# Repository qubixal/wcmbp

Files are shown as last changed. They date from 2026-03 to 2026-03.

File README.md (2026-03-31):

# Water Cooled MacBookPro (WCMBP)
> _this is part of a submission to Blueprint Hack Club._

**Hello!** I'm aiming to DIY the First True* Liquid Cooled Macbook utilising a sub-2.5mm Liquid Cooling Block, as well as creating the first Active Same-Level Hybrid Air-Liquid Cooling System In Consumer Electronics.
The first part of this readme will be a short introduction before this project is explained in more depth.
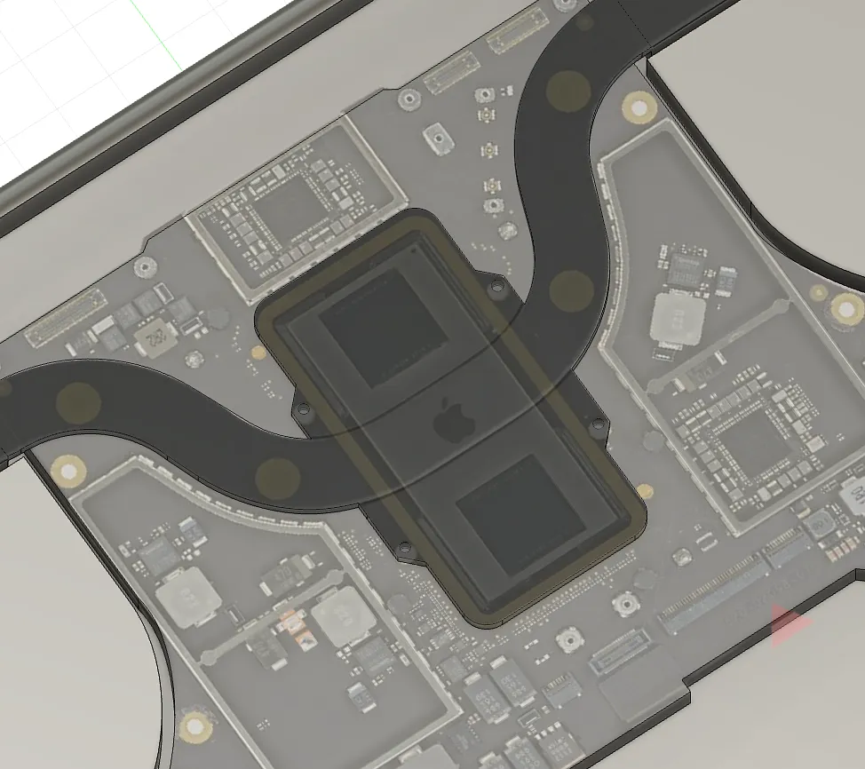
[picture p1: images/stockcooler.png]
Stock Cooler

_render of the stock cooler of the Macbook Pro A2442._

## Function / Use
Similar to a traditional Desktop PC AIO, it features a pump, two fans (one blower one exhaust) and a modified refrigerator heatsink for a small size. 
<br>To use this project, simply plug in the quick disconnect tubing and plug the usbc line into a Macbook that has been prefitted with the heatsink and watch temps drop. 

## Why did I start this project?
I've always wanted to start making something but never found the determination to. 
My first attempt happened last year with me challenging myself to build the smallest drone i could, though those plans were cut short by my lack of experience and shipping problems (negotiating 4 months for the pcb) that destroyed my motivation. 
I wanted to push for a pioneer and revolutionary idea that improves technology, and had an idea at the end of last year to create the world's first true liquid cooled Macbook. 

I hope to make a high quality video out of this project too!
<br> **Thank you for reviewing this project.**

note: this repository is placed under CC BY-NC-ND.

## Hardware (Cooler)
The concept is simple, just pull water over the processor ...
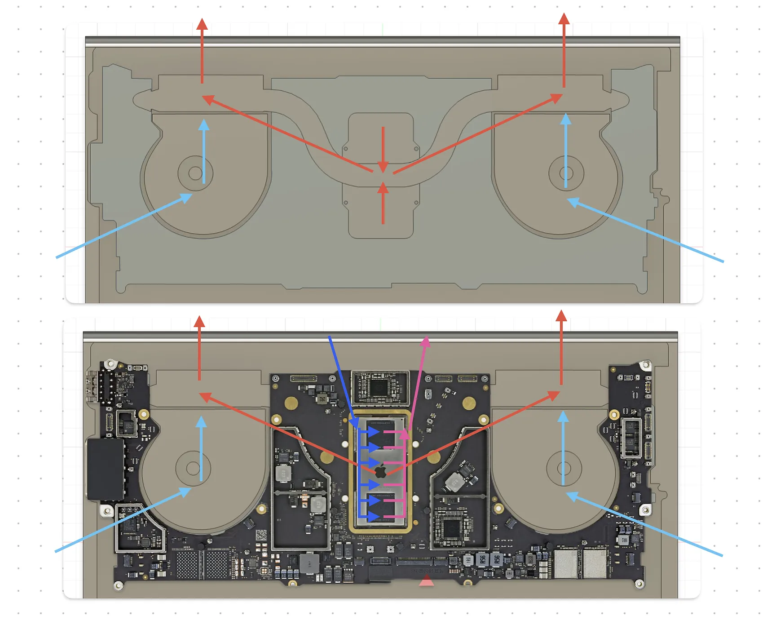
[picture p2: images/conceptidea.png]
Concept Sketch

The first design used parallel channels running from a supply manifold to a drain manifold, shortening single channels to reduce pressure drop.
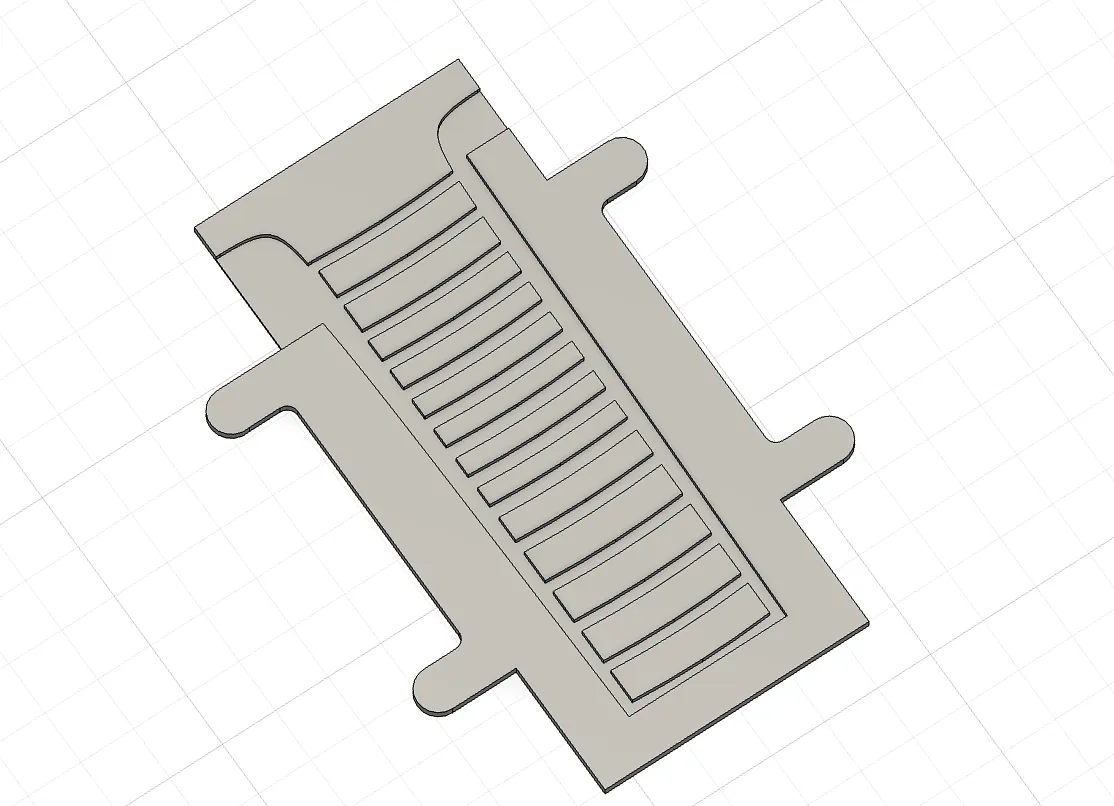
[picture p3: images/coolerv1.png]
First Block Design

To assist with water flow better, the second design smoothed out corners of the first.
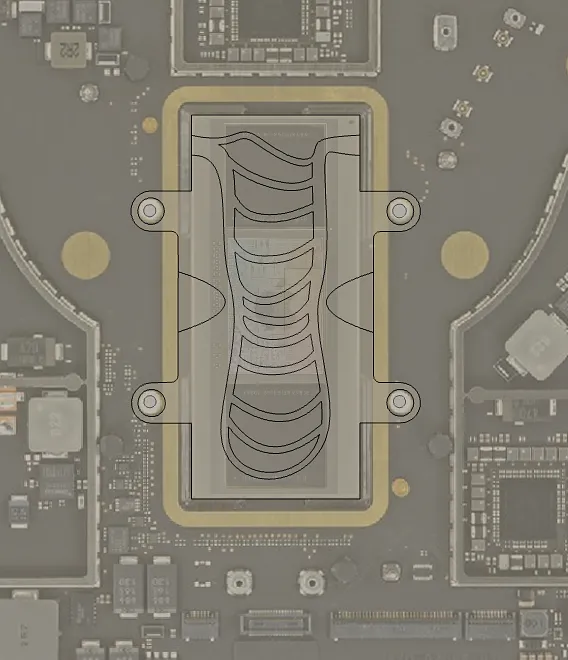
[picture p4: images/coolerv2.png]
Second Block Design


## PCB
This project is powered using the STM32G431CBT6, as my friend also happen to be building a project of his using this chip.
The schematics are as follows.
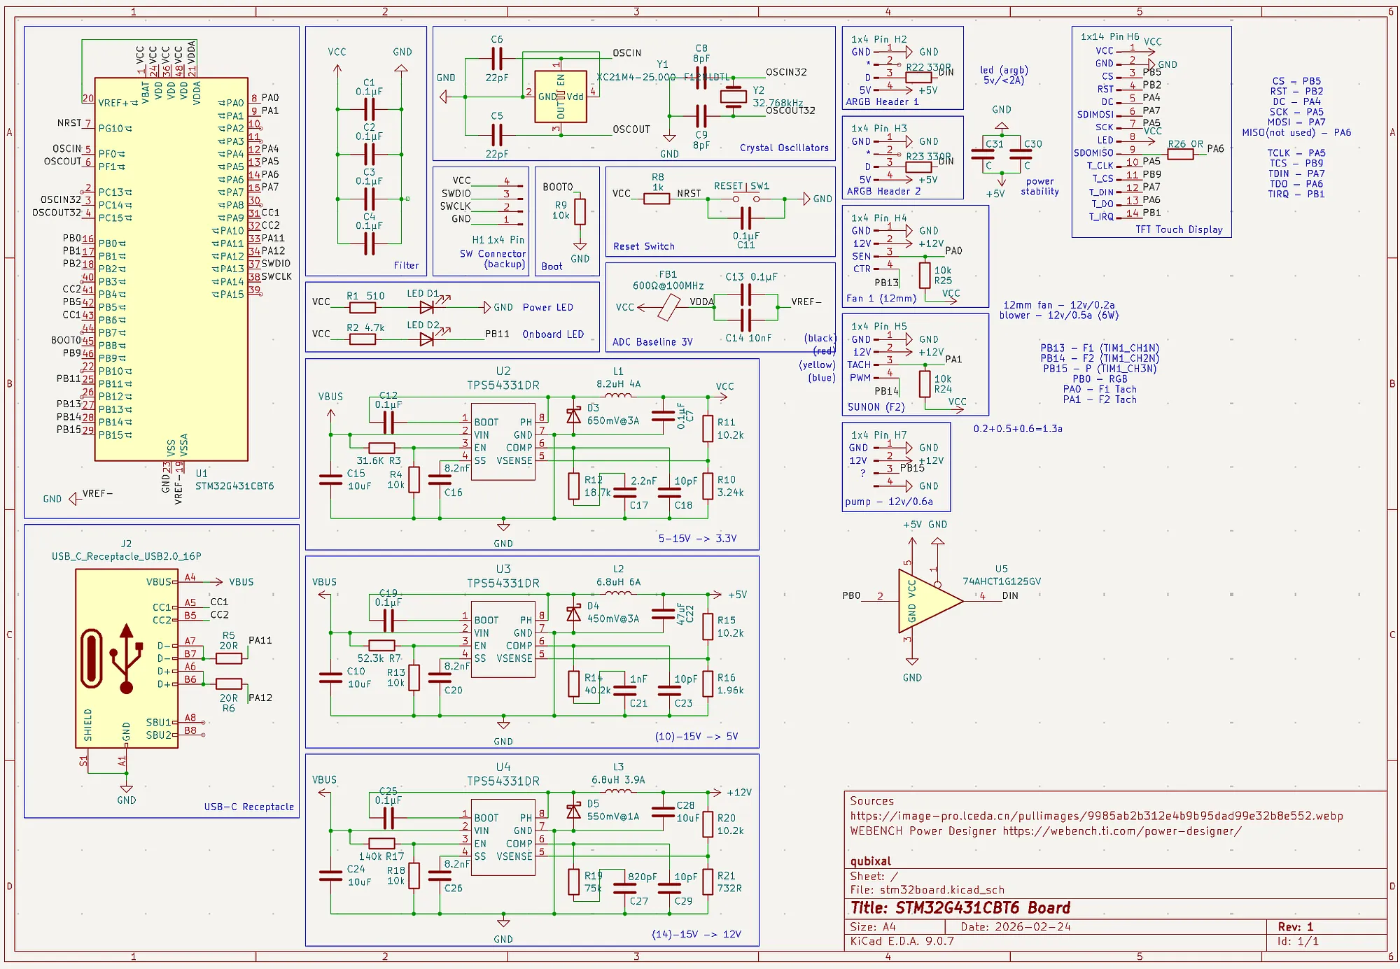
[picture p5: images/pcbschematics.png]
Alt text description

There are a few errors in the schematic design, such as flashing components being forgotten T_T but I'm trying to find a workaround without buying another board.
The wiring is relatively straightforward, all the power supply is at the bottom and the main chip components to the centre, while peripherals are connected to the left.
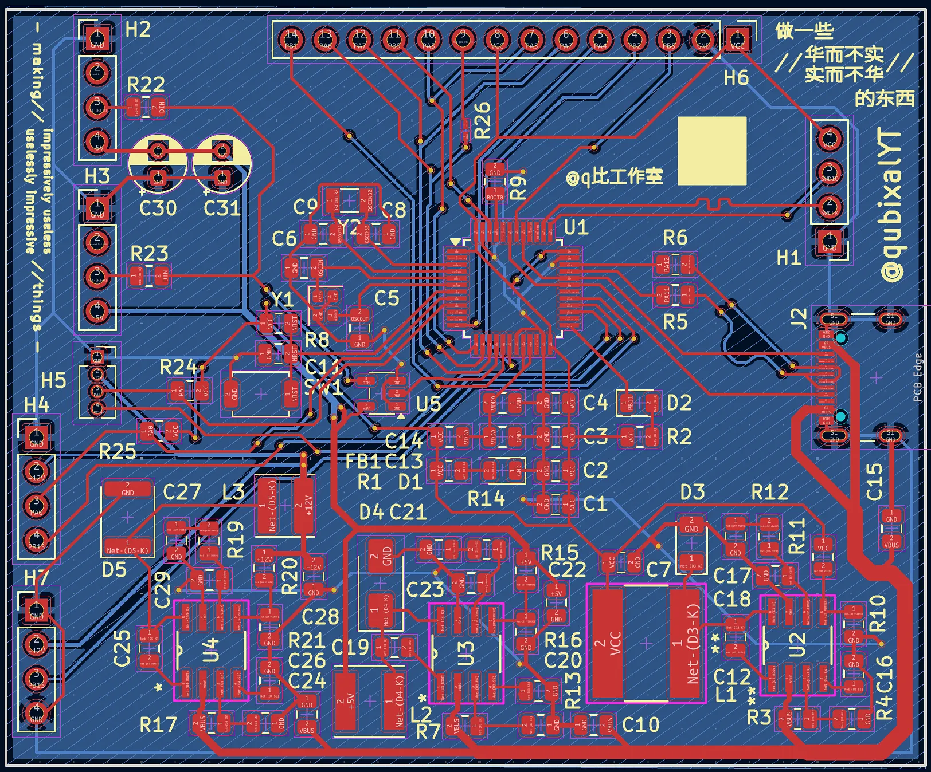
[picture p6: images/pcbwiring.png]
Current wiring

I have finished soldering the board (only rich people can afford stencil T-T) and debugging USB data issues.
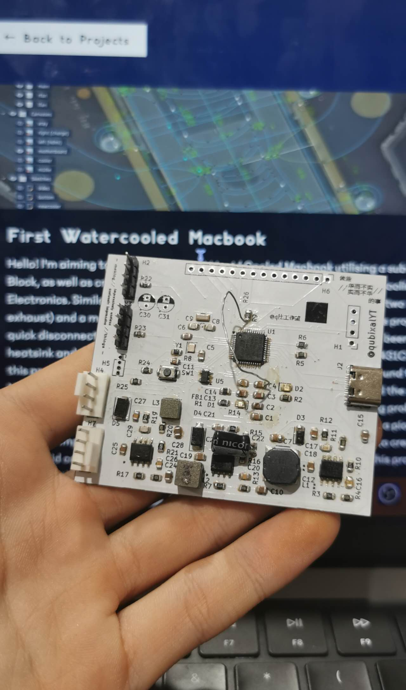
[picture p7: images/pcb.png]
PCB Board


## Case
Original case
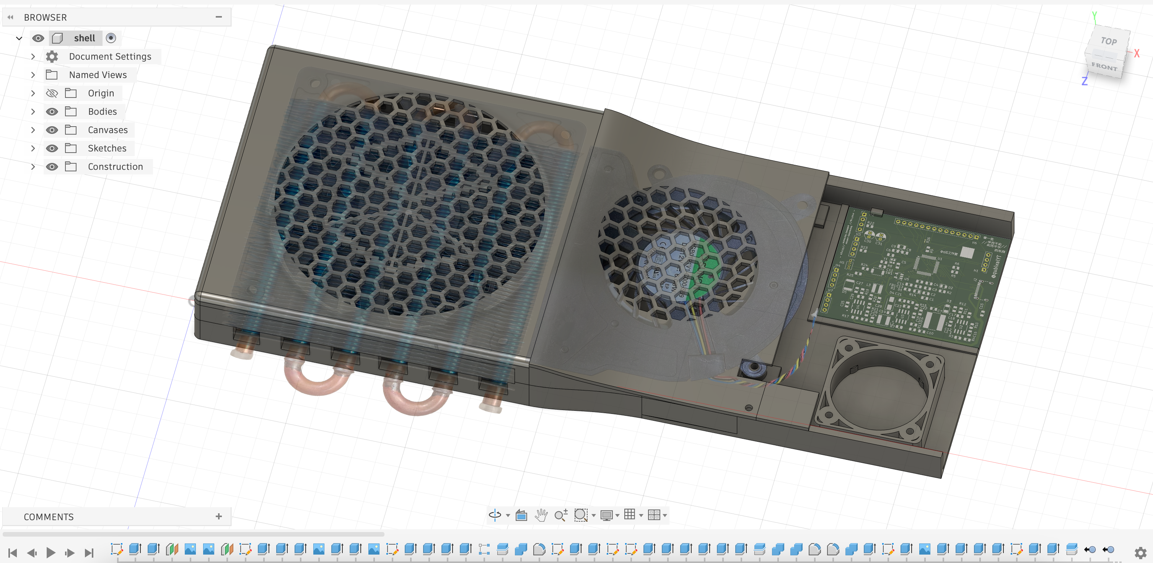
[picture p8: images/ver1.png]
Original casing

Somehow, not a **single** dimension fit. A round of revision and rebuilding the entire project again, ver2 is born.
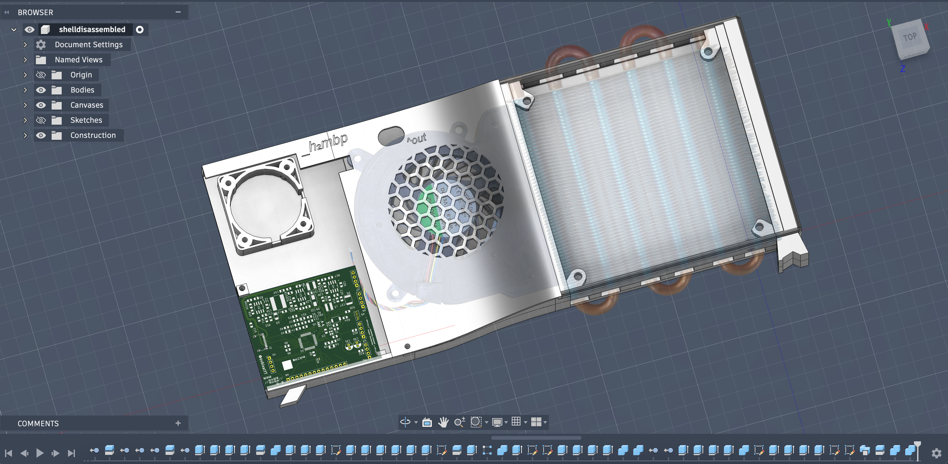
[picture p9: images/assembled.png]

The whole thing can be 3D printed in a few pieces.
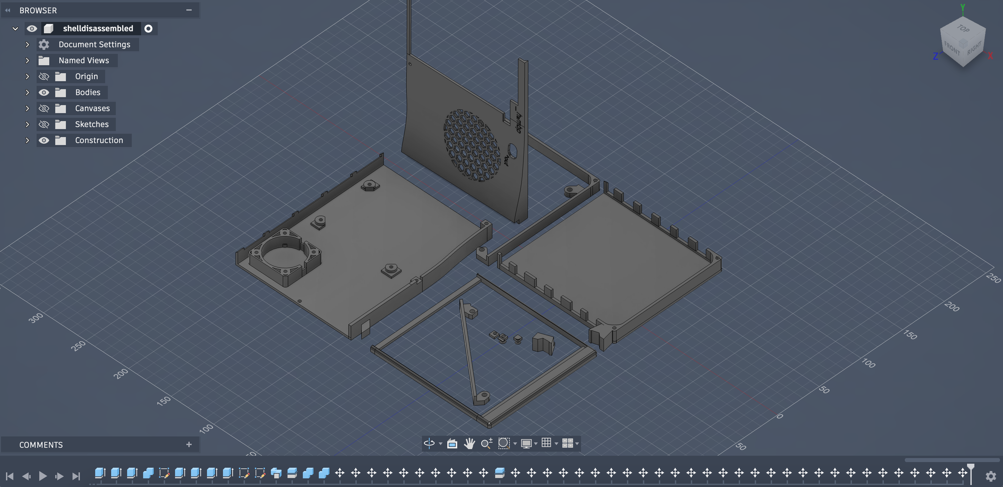
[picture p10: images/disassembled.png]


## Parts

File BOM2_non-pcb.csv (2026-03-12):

Title |  | Multiple | ¥ (CNY) | Link
Barrow 多色PC电脑水冷专用浓缩型冷液 可勾兑1000ML去离子导热液 [交易快照] | Cooling Liquid | 1 | 47.04 | https://item.taobao.com/item.htm?id=655366533729
ARGB机箱装饰5v三针灯条 LED幻彩变色AURA主板神光同步氛围灯带 [交易快照] | ARGB Light | 2 | 33.9 | https://item.taobao.com/item.htm?id=891034010727
亚克力薄片双面加硬亚克力板定制加工diy手工材料裁剪打孔塑料板 [交易快照] | Acrylic Sheet | 1 | 20 | https://item.taobao.com/item.htm?id=1004927544275
笔记本散热铜管超薄导热管平板电脑散热管手机散热冷却管厚:1.0mm [交易快照] | Copper Heatpipe | 4 | 46.4 | https://item.taobao.com/item.htm?id=595853542727
导热胶粘性 导热胶固化粘接导热管铜管 强粘性硅胶ST-988*5克 [交易快照] | Thermal Plaster | 3 | 16.7 | https://item.taobao.com/item.htm?id=19004921338
笔记本电脑散热片纯紫铜散热鳍片翅片热管散热片长度可以DIY改造 [交易快照] | Copper Heatsink | 2 | 44.6 | https://item.taobao.com/item.htm?id=556392308394
彩色液晶屏模块1.8/2.0/2.4/2.8/3.2/3.5寸TFT触摸显示屏SPI彩屏 [交易快照] | TFT Screen | 1 | 36.51 | https://item.taobao.com/item.htm?id=559064754163
704/705/706RTV硅橡胶耐高低温单组份室温固化硅胶驱动电子电器胶 [交易快照] | RTV Silicone | 1 | 11 | https://item.taobao.com/item.htm?id=850193498133
建准原装SUNON MGB0121V1-C000-S99 12V 6.08W一体机散热风扇 [交易快照] | SUNON Fan | 1 | 30 | https://item.taobao.com/item.htm?id=886873268094
笔记本水冷双向止水阀双自锁快速接头模型液压油管接头M5M3螺纹铜 [交易快照] | Fitting 1 | 2 | 89 | https://item.taobao.com/item.htm?id=728084749755
笔记本水冷双向止水阀双自锁快速接头模型液压油管接头M5M3螺纹铜 [交易快照] | Fitting 2 | 2 |  | https://item.taobao.com/item.htm?id=728084749755
不锈钢注塑螺母 M3M4M5M6通孔预埋滚花圆镶嵌国标 直纹 [交易快照] | Fitting 3 | 1 | 7.9 | https://item.taobao.com/item.htm?id=833692892860
不锈钢注塑螺母 M3M4M5M6通孔预埋滚花圆镶嵌国标 直纹 [交易快照] | Fitting 4 | 1 |  | https://item.taobao.com/item.htm?id=833692892860
透明硅胶管 内径8mm 外径9/10/11/12/13/14/16mm食品医用 冷水管 [交易快照] | Tubing (8x10) | 1 | 4.8 | https://item.taobao.com/item.htm?id=38955505261
透明硅胶管软管食品级0.5/1/1.2/1.3/1.6/1.8/2mm毛细管耐高温 [交易快照] | Tubing (1x1.6) | 1 |  | https://item.taobao.com/item.htm?id=40127147980
万向直角宝塔弯头4-M6X1公制螺纹8-M8X1硅胶管管12-M14X1.5冷水管 [交易快照] | Fitting 5 | 2 | 13.57 | https://item.taobao.com/item.htm?id=889054938293
黄铜卡套转快拧直通铜管转气管金属管转软管PU管尼龙管等变径直接 [交易快照] | Fitting 6 | 2 | 16.6 | https://item.taobao.com/item.htm?id=669600619157
小型宝塔1mm插管2mm宝塔1.5 2.5 3 4 1/16管1/8mm 毛细管宝塔接头 [交易快照] | Fitting 7 | 2 | 9.78 | https://item.taobao.com/item.htm?id=803566514786
铜管铝翅片式微型迷你冷凝器小型制冷蒸发器风冷冰箱散热器带风扇 [交易快照] | Radiator | 1 | 37 | https://item.taobao.com/item.htm?id=779852682900
YBO盈博12cm超薄风扇智能调速散热器实力工厂质保一年 [交易快照] | ococoo fan | 1 | 129 | https://item.taobao.com/item.htm?id=1000588580689
YBO盈博水泵工业水冷OC-P67F P67E P27水冷水箱散热医疗美容激光 [交易快照] | Pump | 1 |  | https://item.taobao.com/item.htm?id=827068254010
T2紫铜板加工CNC加工数控车床激光切割线割折弯焊接电镀非标定制 [交易快照] | Custom Copper Block | 1 | 130 | https://item.taobao.com/item.htm?id=994865476571

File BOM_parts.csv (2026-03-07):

Index | LCSC# | MPN | Manufacturer | Package | Customer # | Description | RoHS | Quantity | MOQ | Multiple | Unit Price($) | Extended Price($) | Product Link
1 | C21519 | MPZ2012S601AT000 | TDK | 0805 |  | 600Ω@100MHz 1 Line Ferrite Bead 0805 2A 100mΩ | yes | 10 | 10 | 10 | 0.0245 | 0.25 | https://www.lcsc.com/product-detail/C21519.html
2 | C1710 | CL21B103KBANNNC | Samsung Electro-Mechanics | 0805 |  | 10nF ±10% 50V Ceramic Capacitor X7R 0805 | yes | 50 | 50 | 50 | 0.0065 | 0.33 | https://www.lcsc.com/product-detail/C1710.html
3 | C17402 | 0805W8F1022T5E | UNI-ROYAL | 0805 |  | 10.2kΩ ±1% 125mW 0805 Thick Film Resistor | yes | 100 | 100 | 100 | 0.0024 | 0.24 | https://www.lcsc.com/product-detail/C17402.html
4 | C2933414 | FRC0805F3241TS | FOJAN | 0805 |  | 3.24kΩ ±1% 125mW 0805 Thick Film Resistor | yes | 100 | 100 | 100 | 0.0019 | 0.19 | https://www.lcsc.com/product-detail/C2933414.html
5 | C576982 | CC0805JRNPOCBN100 | YAGEO | 0805 |  | 10pF ±5% 1kV Ceramic Capacitor 0805 | yes | 20 | 20 | 20 | 0.0254 | 0.51 | https://www.lcsc.com/product-detail/C576982.html
6 | C36576 | 0805B222K500NT | FH | 0805 |  | 2.2nF ±10% 50V Ceramic Capacitor X7R 0805 | yes | 20 | 20 | 20 | 0.0051 | 0.10 | https://www.lcsc.com/product-detail/C36576.html
7 | C49655954 | GR0805F18K7T5G00 | GiantOhm | 0805 |  | 125mW 18.7kΩ 150V Thick Film Resistor ±100ppm/℃ ±1% 0805 Chip Resistor - Surface Mount RoHS | yes | 100 | 100 | 100 | 0.0016 | 0.16 | https://www.lcsc.com/product-detail/C49655954.html
8 | C154751 | SBR3U60P1-7 | DIODES | PowerDI-123 |  | 80A 60V 1 Independent 650mV@3A 3A PowerDI-123 Single Diodes RoHS | yes | 5 | 5 | 5 | 0.1357 | 0.68 | https://www.lcsc.com/product-detail/C154751.html
9 | C2041695 | SRN8040-8R2Y | BOURNS | SMD,8.2x7.9mm |  | 3.7A 8.2uH 4A 45mΩ ±30% SMD,8.2x7.9mm Fixed Inductors RoHS | yes | 1 | 1 | 1 | 0.5130 | 0.51 | https://www.lcsc.com/product-detail/C2041695.html
10 | C5128355 | 08055C822KAT2A | Kyocera AVX | 0805 |  | 8.2nF X7R ±10% 50V 0805 Ceramic Capacitors RoHS | yes | 10 | 10 | 10 | 0.0326 | 0.33 | https://www.lcsc.com/product-detail/C5128355.html
11 | C2930231 | FRC0805J103TS | FOJAN | 0805 |  | 10kΩ ±5% 125mW 0805 Thick Film Resistor | yes | 100 | 100 | 100 | 0.0018 | 0.18 | https://www.lcsc.com/product-detail/C2930231.html
12 | C2930156 | FRC0805F3162TS | FOJAN | 0805 |  | 31.6kΩ ±1% 125mW 0805 Thick Film Resistor | yes | 100 | 100 | 100 | 0.0020 | 0.20 | https://www.lcsc.com/product-detail/C2930156.html
13 | C48579607 | 0805X7R106K250NT | AIDE CAPACITOR | 0805 |  | 10uF ±10% 25V Ceramic Capacitor X7R 0805 | yes | 10 | 10 | 10 | 0.0298 | 0.30 | https://www.lcsc.com/product-detail/C48579607.html
14 | C2933465 | FRC0805F5232TS | FOJAN | 0805 |  | 52.3kΩ ±1% 125mW 0805 Thick Film Resistor | yes | 100 | 100 | 100 | 0.0021 | 0.21 | https://www.lcsc.com/product-detail/C2933465.html
15 | C5563736 | MBRA340T3G-FS | FUXINSEMI | SMA(DO-214AC) |  | Diode Independent 40V 3A Surface Mount SMA(DO-214AC) | yes | 5 | 5 | 5 | 0.0733 | 0.37 | https://www.lcsc.com/product-detail/C5563736.html
16 | C49261459 | AAPS0550M6R8F | Coilank | SMD,5.5x5.3mm |  | 6.4A 6.8uH 28.6mΩ 6.6A ±20% SMD,5.5x5.3mm Fixed Inductors RoHS | yes | 1 | 1 | 1 | 0.8602 | 0.86 | https://www.lcsc.com/product-detail/C49261459.html
17 | C2933438 | FRC0805F4022TS | FOJAN | 0805 |  | 40.2kΩ ±1% 125mW 0805 Thick Film Resistor | yes | 100 | 100 | 100 | 0.0020 | 0.20 | https://www.lcsc.com/product-detail/C2933438.html
18 | C1791 | CL21C102JBCNNNC | Samsung Electro-Mechanics | 0805 |  | 1nF ±5% 50V Ceramic Capacitor C0G 0805 | yes | 10 | 10 | 10 | 0.0088 | 0.09 | https://www.lcsc.com/product-detail/C1791.html
19 | C2930163 | FRC0805F1961TS | FOJAN | 0805 |  | 1.96kΩ ±1% 125mW 0805 Thick Film Resistor | yes | 100 | 100 | 100 | 0.0019 | 0.19 | https://www.lcsc.com/product-detail/C2930163.html
20 | C5378487 | FEXL0430A-6R8M | cjiang | SMD,4.1x4.1mm |  | 3.9A 6.8uH 3.6A 74.1mΩ ±20% SMD,4.1x4.1mm Fixed Inductors RoHS | yes | 1 | 1 | 1 | 1.1966 | 1.20 | https://www.lcsc.com/product-detail/C5378487.html
21 | C2837270 | SS14 | JSMSEMI | SMA(DO-214AC) |  | Diode 40V 1A Surface Mount SMA(DO-214AC) | yes | 50 | 50 | 50 | 0.0108 | 0.54 | https://www.lcsc.com/product-detail/C2837270.html
22 | C2933315 | FRC0805F1403TS | FOJAN | 0805 |  | 140kΩ ±1% 125mW 0805 Thick Film Resistor | yes | 100 | 100 | 100 | 0.0019 | 0.19 | https://www.lcsc.com/product-detail/C2933315.html
23 | C17819 | 0805W8F7502T5E | UNI-ROYAL | 0805 |  | 75kΩ ±1% 125mW 0805 Thick Film Resistor | yes | 100 | 100 | 100 | 0.0020 | 0.20 | https://www.lcsc.com/product-detail/C17819.html
24 | C458928 | 0805B821K101CT | Walsin | 0805 |  | 820pF ±10% 100V Ceramic Capacitor X7R 0805 | yes | 50 | 50 | 50 | 0.0016 | 0.08 | https://www.lcsc.com/product-detail/C458928.html
25 | C327296 | RC0805FR-07732RL-S | YAGEO | 0805 |  | 125mW 732Ω 150V Thick Film Resistor ±100ppm/℃ ±1% 0805 Chip Resistor - Surface Mount RoHS | yes | 100 | 100 | 100 | 0.0024 | 0.24 | https://www.lcsc.com/product-detail/C327296.html
26 | C52140417 | 74AHCT1G125GV | MDD(Microdiode Semiconductor) | SOT-23-5L |  | 4.5V~5.5V 1 1 1ns@4.5V 40uA SOT-23-5L Buffers, Drivers, Receivers, Transceivers RoHS | yes | 1 | 1 | 1 | 0.0741 | 0.07 | https://www.lcsc.com/product-detail/C52140417.html
27 | C19795120 | 470533000 | MOLEX | P=2.54mm |  | 1 4P 4 2.54mm 4A 500V 1x4P P=2.54mm Headers, Male Pins RoHS | yes | 5 | 5 | 5 | 0.3702 | 1.85 | https://www.lcsc.com/product-detail/C19795120.html
28 | C529355 | STM32G431CBT6 | ST | LQFP-48(7x7) |  | ARM Cortex-M4F 32 Bit 170MHz 38 LQFP-48(7x7) Microcontrollers RoHS | yes | 5 | 1 | 1 | 3.0856 | 15.43 | https://www.lcsc.com/product-detail/C529355.html
29 | C9865 | TPS54331DR | TI | SOIC-8 |  | 570kHz Buck Adjustable 800mV~25V 3A 3.5V~28V SOIC-8 Voltage Regulators - DC DC Switching Regulators RoHS | yes | 5 | 5 | 5 | 0.2767 | 1.38 | https://www.lcsc.com/product-detail/C9865.html
30 | C5368707 | 1.25mm-4P ZZ-MS | SHOU HAN | Through Hole,P=1.25mm |  | Connector Header 4 position 1.25mm Pitch 1A Through Hole -25℃~+85℃ | yes | 20 | 20 | 20 | 0.0230 | 0.46 | https://www.lcsc.com/product-detail/C5368707.html
31 | C97606 | SC-32S32.768kHz20PPM12.5pF | Seiko | SMD3215-2P |  | Crystal 32.768kHz ±20ppm 12.5pF SMD3215-2P | yes | 5 | 5 | 5 | 0.1828 | 0.91 | https://www.lcsc.com/product-detail/C97606.html
32 | C49234124 | HX 3x4x2-2P-1.6N TACTILE SWITCH | hanxia | SMD,4x3mm |  | Tactile Switch SPST 160gf 2mm SMD (SMT) Tab 4mm x 3mm Surface Mount | yes | 20 | 20 | 20 | 0.0192 | 0.38 | https://www.lcsc.com/product-detail/C49234124.html
33 | C17673 | 0805W8F4701T5E | UNI-ROYAL | 0805 |  | 4.7kΩ ±1% 125mW 0805 Thick Film Resistor | yes | 100 | 100 | 100 | 0.0019 | 0.19 | https://www.lcsc.com/product-detail/C17673.html
34 | C25293 | 0805W8J0200T5E | UNI-ROYAL | 0805 |  | 20Ω ±5% 125mW 0805 Thick Film Resistor | yes | 100 | 100 | 100 | 0.0019 | 0.19 | https://www.lcsc.com/product-detail/C25293.html
35 | C25170728 | YLED0805G | YONGYUTAI | 0805 |  | Emerald Green 525nm LED Indication - Discrete 2.4V~3.1V 0805 | yes | 50 | 50 | 50 | 0.0084 | 0.42 | https://www.lcsc.com/product-detail/C25170728.html
36 | C476766 | C0805B104K500NT | TORCH | 0805 |  | 100nF ±10% 50V Ceramic Capacitor X7R 0805 | yes | 25 | 25 | 25 | 0.0034 | 0.09 | https://www.lcsc.com/product-detail/C476766.html
37 | C28323 | CL21B105KBFNNNE | Samsung Electro-Mechanics | 0805 |  | 1uF ±10% 50V Ceramic Capacitor X7R 0805 | yes | 20 | 20 | 20 | 0.0100 | 0.20 | https://www.lcsc.com/product-detail/C28323.html
38 | C519944 | CC0805CRNPO9BN8R0 | YAGEO | 0805 |  | 8pF 50V Ceramic Capacitor 0805 | yes | 50 | 50 | 50 | 0.0083 | 0.42 | https://www.lcsc.com/product-detail/C519944.html
39 | C1804 | CL21C220JBANNNC | Samsung Electro-Mechanics | 0805 |  | 22pF ±5% 50V Ceramic Capacitor C0G 0805 | yes | 50 | 50 | 50 | 0.0096 | 0.48 | https://www.lcsc.com/product-detail/C1804.html
40 | C3021118 | TPMIC5365-3.3YC5 | TECH PUBLIC | SOT-353 |  | 3.3V 5.5V Positive Fixed SOT-353 Voltage Regulators - Linear, Low Drop Out (LDO) Regulators RoHS | yes | 10 | 5 | 5 | 0.1359 | 1.36 | https://www.lcsc.com/product-detail/C3021118.html
41 | C3034312 | XC21M4-25.000-F12NLDTL | HCI | SMD2016-4P |  | Crystal 25MHz ±10ppm 12pF 100Ω SMD2016-4P | yes | 10 | 5 | 5 | 0.0898 | 0.90 | https://www.lcsc.com/product-detail/C3034312.html

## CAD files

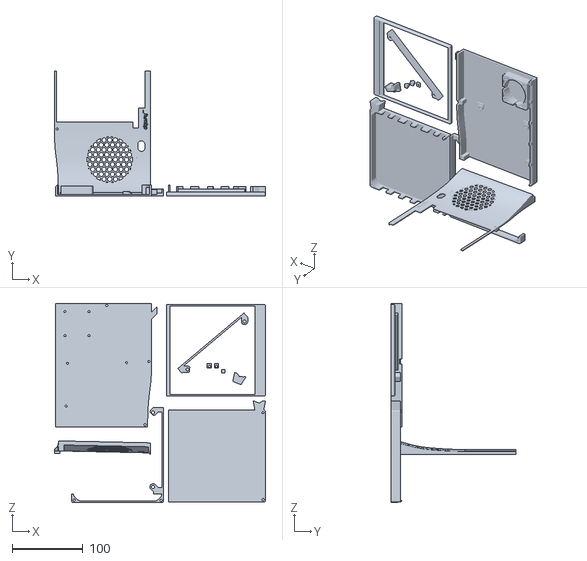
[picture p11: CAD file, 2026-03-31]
shelldisassembled.stl
298.9 x 177.8 x 282.4

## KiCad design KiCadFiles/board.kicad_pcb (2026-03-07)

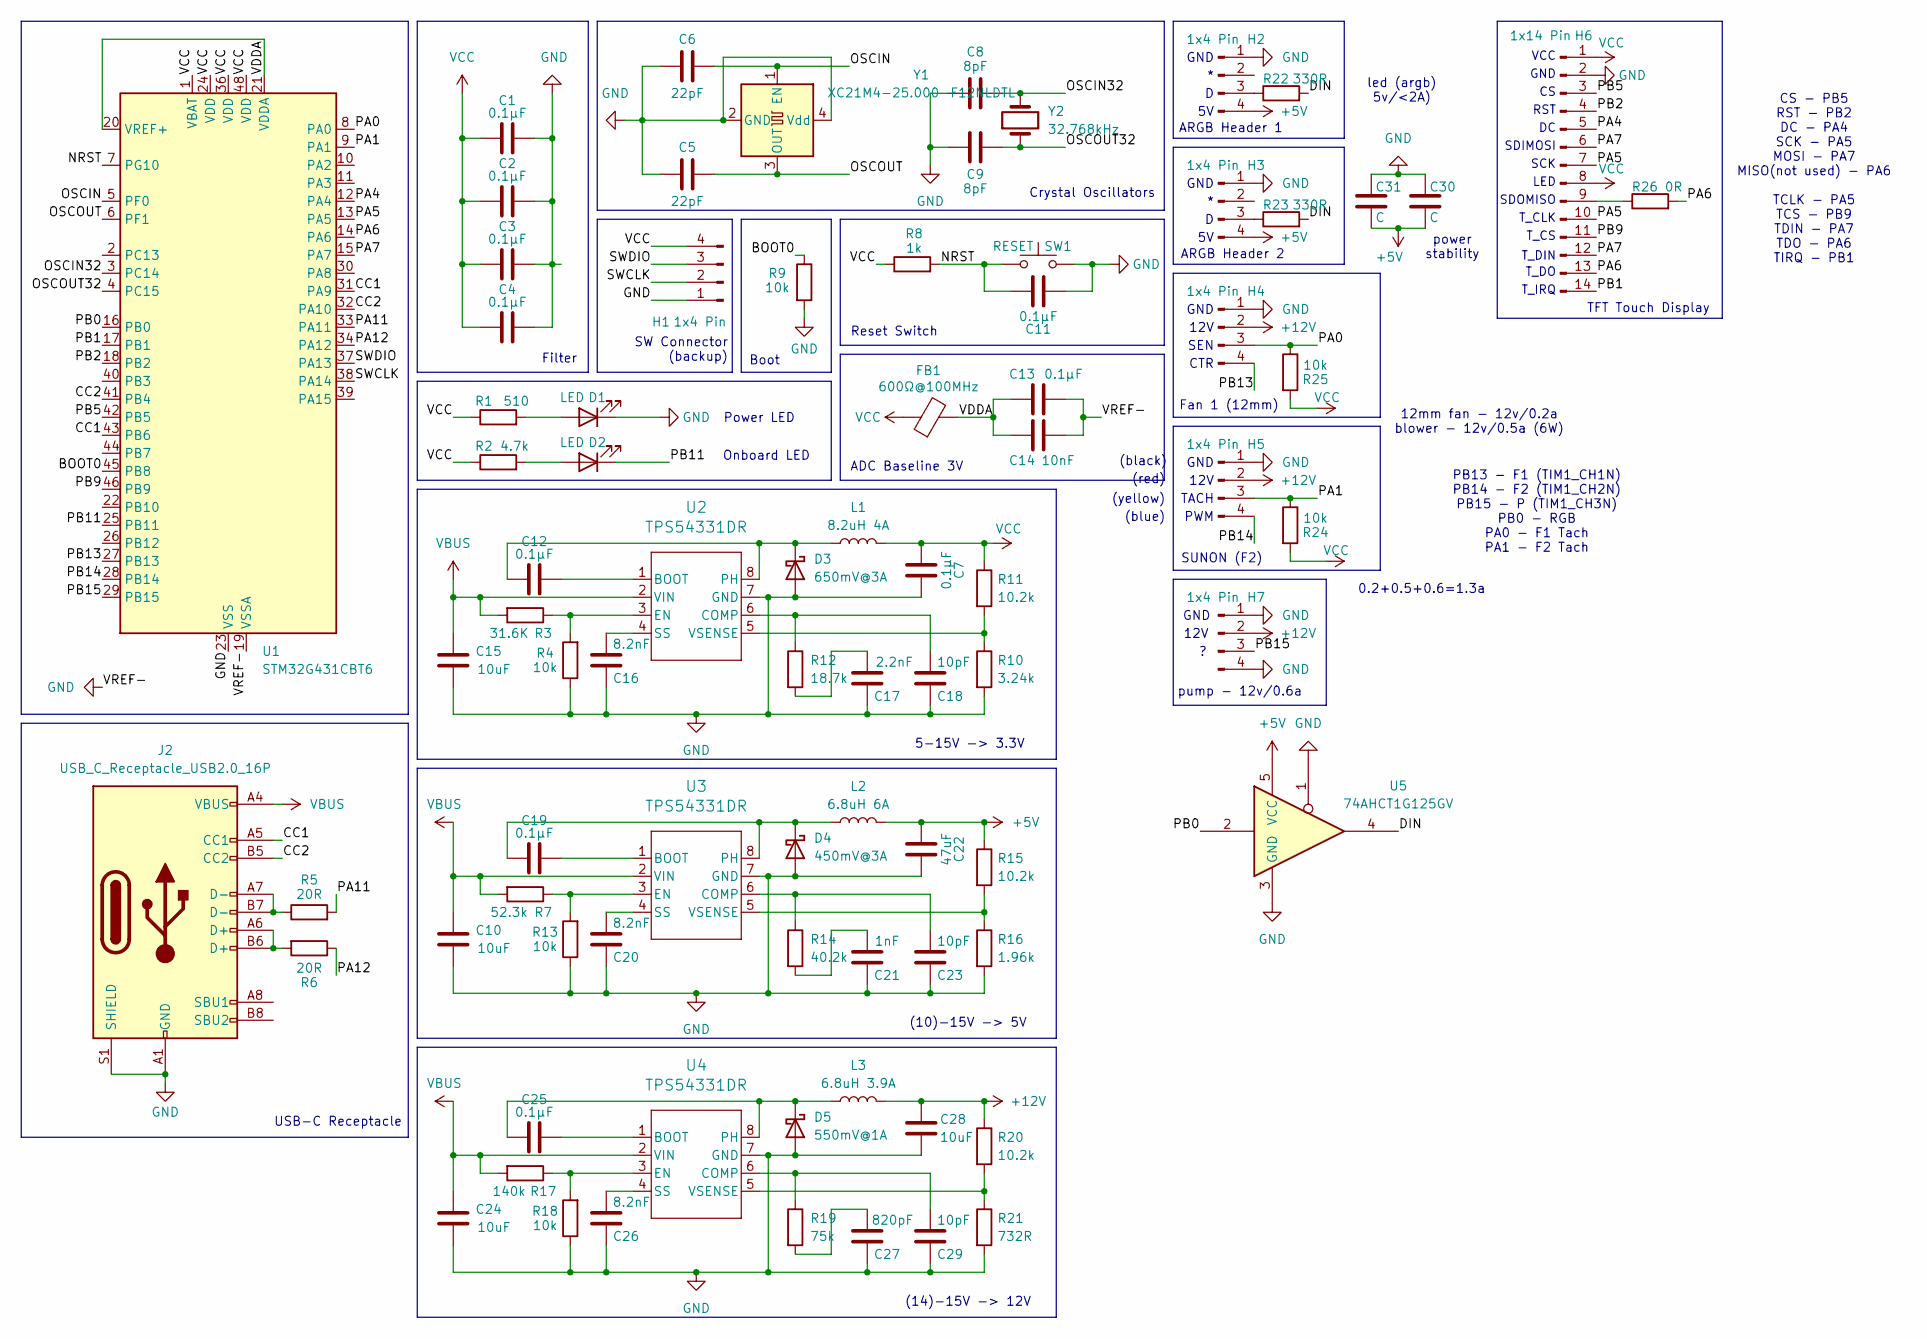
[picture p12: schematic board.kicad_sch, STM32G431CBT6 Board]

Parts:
C1, C2, C3, C4, C7, C11, C12, C13, C19, C25: 0.1μF; C_0805_2012Metric
C5, C6: 22pF; C_0805_2012Metric
C8, C9: 8pF; C_0805_2012Metric
C10, C15, C24, C28: 10uF; C_0805_2012Metric
C14: 10nF; C_0805_2012Metric
C16, C20, C26: 8.2nF; C_0805_2012Metric
C17: 2.2nF; C_0805_2012Metric
C18, C23, C29: 10pF; C_0805_2012Metric
C21: 1nF; C_0805_2012Metric
C22: 47uF; C_0805_2012Metric
C27: 820pF; C_0805_2012Metric
C30, C31: C; CP_Radial_D4.0mm_P2.00mm
D1, D2: LED; LED_0805_2012Metric
D3: 650mV@3A; D_1206_3216Metric
D4: 450mV@3A; D_SMA
D5: 550mV@1A; D_1812_4532Metric
FB1: 600Ω@100MHz; C_0805_2012Metric
H1, H2, H3, H4, H7: 1x4 Pin; PinHeader_1x04_P2.54mm_Vertical
H5: 1x4 Pin; PinSocket_1x04_P1.27mm_Vertical
H6: 1x14 Pin; PinHeader_1x14_P2.54mm_Vertical
J2: USB_C_Receptacle_USB2.0_16P; USB_C_Receptacle_GCT_USB4105-xx-A_16P_TopMnt_Horizontal
L1: 8.2uH 4A; BOURNS_SRN8040
L2: 6.8uH 6A; L_Taiyo-Yuden_MD-5050
L3: 6.8uH 3.9A; L_Changjiang_FTC404030S
R1: 510; R_0805_2012Metric
R2: 4.7k; R_0805_2012Metric
R3: 31.6K; R_0805_2012Metric
R4, R9, R13, R18, R24, R25: 10k; R_0805_2012Metric
R5, R6: 20R; R_0805_2012Metric
R7: 52.3k; R_0805_2012Metric
R8: 1k; R_0805_2012Metric
R10: 3.24k; R_0805_2012Metric
R11, R15, R20: 10.2k; R_0805_2012Metric
R12: 18.7k; R_0805_2012Metric
R14: 40.2k; R_0805_2012Metric
R16: 1.96k; R_0805_2012Metric
R17: 140k; R_0805_2012Metric
R19: 75k; R_0805_2012Metric
R21: 732R; R_0805_2012Metric
R22, R23: 330R; R_0805_2012Metric
R26: 0R; R_0201_0603Metric_Pad0.64x0.40mm_HandSolder
SW1: RESET; SW_SPST_TS-1088-xR020
U1: STM32G431CBT6; LQFP-48_7x7mm_P0.5mm
U2, U3, U4: TPS54331DR; TPS54331
U5: 74AHCT1G125GV; SOT-23-5
Y1: XC21M4-25.000-F12NLDTL; Crystal_SMD_2016-4Pin_2.0x1.6mm
Y2: 32.768kHz; Crystal_SMD_3215-2Pin_3.2x1.5mm

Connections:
+5V: C22.1, C30.2, C31.2, H2.4 (5V), H3.4 (5V), L2.2, R15.1, U5.5 (VCC)
+12V: C28.2, H4.2 (*), H5.2 (*), H7.2 (*), L3.2, R20.1
/BOOT0: R9.1, U1.45 (PB8)
/CC1: J2.A5 (CC1), U1.31 (PA9), U1.43 (PB6)
/CC2: J2.B5 (CC2), U1.32 (PA10), U1.41 (PB4)
/DIN: R22.2, R23.2, U5.4
/NRST: C11.2, R8.2, SW1.1, U1.7 (PG10)
/OSCIN: C6.2, U1.5 (PF0), Y1.1 (EN)
/OSCIN32: C8.2, U1.3 (PC14), Y2.2
/OSCOUT: C5.2, U1.6 (PF1), Y1.3 (OUT)
/OSCOUT32: C9.2, U1.4 (PC15), Y2.1
/PA0: H4.3 (D), R25.1, U1.8 (PA0)
/PA1: H5.3 (D), R24.1, U1.9 (PA1)
/PA4: H6.5, U1.12 (PA4)
/PA5: H6.7, H6.10, U1.13 (PA5)
/PA6: H6.13, R26.2, U1.14 (PA6)
/PA7: H6.6, H6.12, U1.15 (PA7)
/PA11: R5.2, U1.33 (PA11)
/PA12: R6.1, U1.34 (PA12)
/PB0: U1.16 (PB0), U5.2
/PB1: H6.14, U1.17 (PB1)
/PB2: H6.4, U1.18 (PB2)
/PB5: H6.3, U1.42 (PB5)
/PB9: H6.11, U1.46 (PB9)
/PB11: D2.1 (K), U1.25 (PB11)
/PB13: H4.4 (5V), U1.27 (PB13)
/PB14: H5.4 (5V), U1.28 (PB14)
/PB15: H7.3 (D), U1.29 (PB15)
/SWCLK: H1.2, U1.38 (PA14)
/SWDIO: H1.3, U1.37 (PA13)
/VDDA: C13.1, C14.2, FB1.2, U1.20 (VREF+), U1.21 (VDDA)
GND: C1.2, C2.2, C3.2, C4.2, C5.1, C6.1, C7.2, C8.1, C9.1, C10.1, C11.1, C13.2, C14.1, C15.1, C16.2, C17.2, C18.2, C20.2, C21.2, C22.2, C23.2, C24.1, C26.2, C27.2, C28.1, C29.2, C30.1, C31.1, D1.1 (K), D3.2 (A), D4.2 (A), D5.2 (A), H1.1, H2.1 (GND), H3.1 (GND), H4.1 (GND), H5.1 (GND), H6.2, H7.1 (GND), H7.4 (5V), J2.A1 (GND), J2.A12 (GND), J2.B1 (GND), J2.B12 (GND), J2.S1 (SHIELD), R4.1, R9.2, R10.2, R13.1, R16.2, R18.1, R21.2, SW1.2, U1.19 (VSSA), U1.23 (VSS), U1.35 (VSS), U1.47 (VSS), U2.7 (GND), U3.7 (GND), U4.7 (GND), U5.1, U5.3 (GND), Y1.2 (GND), Y1.4 (Vdd)
unnamed: C17.1, R12.2
unnamed: C21.1, R14.2
unnamed: C27.1, R19.2
unnamed: D1.2 (A), R1.2
unnamed: D2.2 (A), R2.2
unnamed: C12.1, D3.1 (K), L1.1, U2.8 (PH)
unnamed: C19.1, D4.1 (K), L2.1, U3.8 (PH)
unnamed: C25.1, D5.1 (K), L3.1, U4.8 (PH)
unnamed: H2.3 (D), R22.1
unnamed: H3.3 (D), R23.1
unnamed: H6.9, R26.1
unnamed: J2.A6 (D+), J2.B6 (D+), R6.2
unnamed: J2.A7 (D-), J2.B7 (D-), R5.1
unnamed: C12.2, U2.1 (BOOT)
unnamed: C18.1, R12.1, U2.6 (COMP)
unnamed: R3.1, R4.2, U2.3 (EN)
unnamed: C16.1, U2.4 (SS)
unnamed: R10.1, R11.2, U2.5 (VSENSE)
unnamed: C19.2, U3.1 (BOOT)
unnamed: C23.1, R14.1, U3.6 (COMP)
unnamed: R7.1, R13.2, U3.3 (EN)
unnamed: C20.1, U3.4 (SS)
unnamed: R15.2, R16.1, U3.5 (VSENSE)
unnamed: C25.2, U4.1 (BOOT)
unnamed: C29.1, R19.1, U4.6 (COMP)
unnamed: R17.1, R18.2, U4.3 (EN)
unnamed: C26.1, U4.4 (SS)
unnamed: R20.2, R21.1, U4.5 (VSENSE)
VBUS: C10.2, C15.2, C24.2, J2.A4 (VBUS), J2.A9 (VBUS), J2.B4 (VBUS), J2.B9 (VBUS), R3.2, R7.2, R17.2, U2.2 (VIN), U3.2 (VIN), U4.2 (VIN)
VCC: C1.1, C2.1, C3.1, C4.1, C7.1, FB1.1, H1.4, H6.1, H6.8, L1.2, R1.1, R2.1, R8.1, R11.1, R24.2, R25.2, U1.1 (VBAT), U1.24 (VDD), U1.36 (VDD), U1.48 (VDD)

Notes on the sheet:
Reset Switch
SDIMOSI
(yellow)
CS - PB5 RST - PB2 DC - PA4 SCK - PA5 MOSI - PA7 MISO(not used) - PA6 TCLK - PA5 TCS - PB9 TDIN - PA7 TDO - PA6 TIRQ - PB1
GND
Fan 1 (12mm)
0.2+0.5+0.6=1.3a
USB-C Receptacle
RST
SUNON (F2)
Power LED
ARGB Header 1
12V
(14)-15V -> 12V
5-15V -> 3.3V
ARGB Header 2
SDOMISO
TACH
12mm fan - 12v/0.2a blower - 12v/0.5a (6W)
(10)-15V -> 5V
ADC Baseline 3V
Boot
(black)
SCK
Filter
(blue)
T_DIN
(red)
CTR
T_CS
T_CLK
VCC
PWM
Onboard LED
T_DO
pump - 12v/0.6a
SW Connector (backup)
LED
TFT Touch Display
T_IRQ

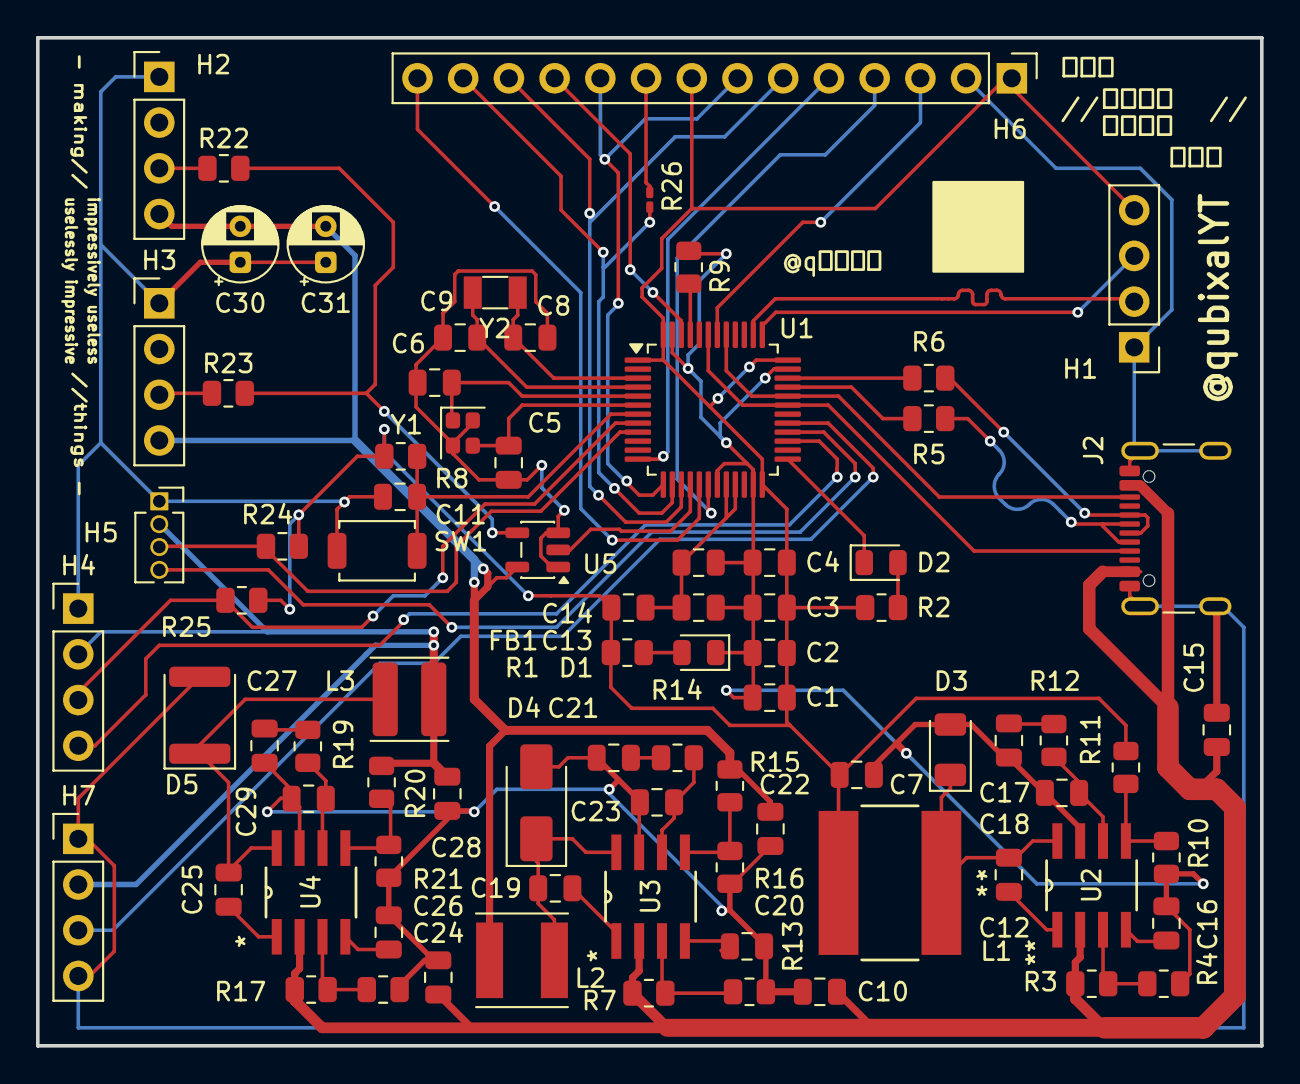
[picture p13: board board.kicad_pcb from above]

Board: 2 copper layers, 68.0 x 56.0 mm, 82 parts (0 on the bottom side), 62 nets.

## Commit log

2026-03-07 Add files via upload
    pcb/bom parts files
    [BOM_parts.csv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]
2026-03-07 kicad files
    [board.kicad_pcb, board.kicad_sch]
2026-03-12 case 3d file
    [shelldisassembled.stl]
2026-03-12 non pcb bom
    [BOM2_non-pcb.csv]
